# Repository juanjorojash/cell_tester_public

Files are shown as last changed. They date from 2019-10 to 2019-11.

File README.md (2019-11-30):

Electrochemical Cell Charger/Discharger/Tester
============

### Most recent version of this repository can be found in: ###

* [GitHub](https://github.com/juanjorojash/cell_tester_public/)

### Documentation ###

* Full documentation in HTLM version can be found in **[repository directory]/documentation/htlm/index.htlm**

### What is this repository for? ###

* This repository was created to be used in conjuction with the integrated system known as "Charger_discharger.V5". The latest . It was created to control the PIC16F1786 installed for feedback control and serial logging.
* Hardware version: Charger_discharger.V5
* PCB design files  located in **[repository directory]/board/**

### How do I get set up? ###

* Connect usign serial cable model "TTL-232R-5V-AJ". 
* **Serial terminal** Start with the following settings BR:57600 kbps, Data: 8 bit, Parity: none, Stop bits: 1, Flow control: none. Press "ESC" to restart and show the main menu. Set the desired configuration following the instructions.
* **LabView logger program** A program for receiving, saving and plotting the test data is included in the repository, in the directory **labview_logger/logger.exe**. The following programs are needed in order to run this program in a PC that **does not** have LabView installed:
	* [LabVIEW Run-Time Engine 2016 - (64-bit)](http://www.ni.com/download/labview-run-time-engine-2016/6067/en/) 
	* [NI-VISA Run-Time Engine 16.0](http://www.ni.com/download/ni-visa-run-time-engine-16.0/6188/en/)
The program creates the directory **c:/logger_data** to store the data.

### Contribution guidelines ###

* If you want to propose a review or need to modify the code for any reason first fork this [repository](https://github.com/juanjorojash/cell_tester_public/) in your PC and create a new branch for your changes. Once your changes are complete and fully tested ask the administrator permission to push this new branch into the source.
* If you just want to do local changes instead you can download a zip version of the repository and do all changes locally in your PC. 

### Who do I talk to? ###

* [Juan J. Rojas](mailto:juan.rojas@itcr.ac.cr)

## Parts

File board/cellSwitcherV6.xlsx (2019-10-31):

Part List |  |  |  |  |  |  |  | To take from inventory |  |  |  |  |  | To buy |  |  |  |  |  |  |  |  |  |  |  | FOR RS |  | FOR PBAN |  |  |  |  |  | SMD / DIP | Package
Qty | Name | Device | Value | Package | Parts | SMD / DIP | Pads / Pins | Bag | Available | Need | Balance | Specifications | Manufacturer | Vendor | Vendor SN | Manufacurer PN | Package type | Needed | Minimum | Actual | Inventory before | Inventory now | Unit cost | Total
4 | NPN transistor | BC818K-40 |  | SOT-23 | BJT1, BJT2, BJT3, BJT4 | SMD | 3 | A28 | 93 | 30 | 63 |  | Infineon |  |  | BC818K40E6327HTSA1 |  |  |  |  |  |  |  |  |  |  |  | Infineon | NPN transistor | BC818K40E6327HTSA1 | BJT1, BJT2, BJT3, BJT4 | 4 | 3 | SMD | SOT-23
1 | Non-polarized capacitor | NONPOL_CAP-0603 | 1n | C0603 | C1 | SMD | 2 | B37 | 93 | 12 | 81 |  | TDK |  |  | C1608X7R1H102K080AE |  |  |  |  |  |  |  |  |  |  |  | TDK | Non-polarized capacitor | C1608X7R1H102K080AE | C1 | 1 | 2 | SMD | C0603
2 | Non-polarized capacitor | NONPOL_CAP-0603 | 0.1u | C0603 | C2, C3 | SMD | 2 | B03 | 93 | 18 | 75 |  | TDK |  |  | C1608X8R1H104K080AB |  |  |  |  |  |  |  |  |  |  |  | TDK | Non-polarized capacitor | C1608X8R1H104K080AB | C2, C3 | 2 | 2 | SMD | C0603
1 | Non-polarized capacitor | NONPOL_CAP-0603 | 0.33u | C0603 | C4 | SMD | 2 | A25 | 34 | 12 | 22 |  | Murata |  |  | GRM21BR71C334KA01L |  |  |  |  |  |  |  |  |  |  |  | Murata | Non-polarized capacitor | GRM21BR71C334KA01L | C4 | 1 | 2 | SMD | C0603
1 | Non-polarized capacitor | NONPOL_CAP-0603 | 1u | C0603 | C5 | SMD | 2 | B04 | 8 | 12 | -4 |  | TDK |  |  | CGA4J3X7R1H105K125AB |  |  |  |  |  |  |  |  |  |  |  | TDK | Non-polarized capacitor | CGA4J3X7R1H105K125AB | C5 | 1 | 2 | SMD | C0603
1 | Non-polarized capacitor | NONPOL_CAP-0603 | 10u | C0603 | C6 | SMD | 2 | B06 | 32 | 12 | 20 |  | Murata |  |  | GRM188R61E106MA73D |  |  |  |  |  |  |  |  |  |  |  | Murata | Non-polarized capacitor | GRM188R61E106MA73D | C6 | 1 | 2 | SMD | C0603
2 | Li-Ion cell holder | 2_18650_HOLDER |  |  | CH1, CH2 | DIP | 2 | C1 | 12 | 9 | 3 |  | Keystone |  |  | 1049P |  |  |  |  |  |  |  |  |  |  |  | Keystone | Li-Ion cell holder | 1049P | CH1, CH2 | 2 | 2 | DIP
2 | Ni-MH cell holder | 2_AA_HOLDER |  |  | CH1, CH2 | DIP | 2 |  |  |  |  | Bulgin PCB mounting battery holder, AA size X 1 BX0035 AA battery 1 PCB | Bulgin | RS | 489-908 | BX0035 |  | 9 | 1 | 9 | 0 | 0 | ¥392.00 | ¥3528.00 | https://jp.rs-online.com/web/p/battery-holders-mounts/0489908/ | 489-908 | 9 | Bulgin | Ni-MH cell holder | BX0035 | CH1, CH2 | 2 | 2 | DIP
1 | Connector | TMM-110-01-F-D-RA |  |  | CON1 | DIP | 20 |  |  |  |  | 20 Positions Header Connector 0.079 "(2.00 mm) Through Hole, Right Angle Gold | SAMTEC | Digi-Key | TMM-110-01-FD-RA-ND | TMM-110-01-FD-RA |  | 12 | 1 | 12 | 0 | 0 | ¥229.00 | ¥2748.00 | https://www.digikey.jp/product-detail/ja/samtec-inc/TMM-110-01-F-D-RA/TMM-110-01-F-D-RA-ND/2685424 | TMM-110-01-FD-RA-ND | 12 | SAMTEC | Connector | TMM-110-01-FD-RA | CON1 | 1 | 20 | DIP
4 | Switching diode | BAQ133-GS08 |  | SOD08 | D1, D2, D3, D4 | SMD | 2 | A44 | 78 | 30 | 48 |  | Vishay |  |  | BAQ133-GS08 |  |  |  |  |  |  |  |  |  |  |  | Vishay | Switching diode | BAQ133-GS08 | D1, D2, D3, D4 | 4 | 2 | SMD | SOD08
1 | Fuse holder | FUSEHOLDER |  |  | F1 | DIP | 2 | A38 | 10 | 12 | -2 | Schurter PCB mounting fuse holder 10A for 5 x 20 mm cartridge fuse 250V ac 0031.8201 | Schurter | RS | 176-9047 | 31.8201 |  | 2 | 10 | 10 | 0 | 8 | ¥97.40 | ¥974.00 | https://jp.rs-online.com/web/p/pcb-mounts/1769047/ | 176-9047 | 10 | Schurter | Fuse holder | 31.8201 | F1 | 1 | 2 | DIP
4 | Relay | RTE24005F |  |  | K1, K2, K3, K4 | DIP | 8 | A66 | 24 | 30 | -6 | TE Connectivity Relay 5V dc, 2c contact PCB mounting type | TE Connectivity | RS | 782-1261 | RTE24005F |  | 6 | 1 | 6 | 0 | 0 | ¥316.00 | ¥1896.00 | https://jp.rs-online.com/web/p/pcb-mounts/1769047/ | 782-1261 | 6 | TE Connectivity | Relay | RTE24005F | K1, K2, K3, K4 | 4 | 8 | DIP
4 | LED | LGR971 |  | SML0805 | LED1, LED2, LED3, LED4 | SMD | 2 | A49 | 32 | 30 | 2 |  | OSRAM Opto Semiconductors |  |  | LGR971 |  |  |  |  |  |  |  |  |  |  |  | OSRAM Opto Semiconductors | LED | LGR971 | LED1, LED2, LED3, LED4 | 4 | 2 | SMD | SML0805
1 | Muxer | ADG704BRM |  | MSOP10 | MUX1 | SMD | 10 | A52 | 7 | 12 | -5 | Analog Devices Single 4: 1 Multiplexer 3 V, 5 V, 10-Pin MSOP | Analog Devices | RS | 523-8761 | ADG704BRMZ |  | 5 | 1 | 5 | 0 | 0 | ¥327.00 | ¥1635.00 | https://jp.rs-online.com/web/p/multiplexer-switch-ics/5238761/ | 523-8761 | 5 | Analog Devices | Muxer | ADG704BRMZ | MUX1 | 1 | 10 | SMD | MSOP10
1 | NAND gate | SN74LVC2G00DCUT |  | VSSOP-8 | NAND1 | SMD | 8 | A48 | 16 | 12 | 4 |  | Texas Instruments |  |  | SN74LVC2G00DCUT |  |  |  |  |  |  |  |  |  |  |  | Texas Instruments | NAND gate | SN74LVC2G00DCUT | NAND1 | 1 | 8 | SMD | VSSOP-8
1 | OptoCoupler | PS2502-4 |  | DIL16 | OK1 | DIP | 16 | A50 | 12 | 12 | 0 |  | Renesas Electronics |  |  | PS2502-4-A |  |  |  |  |  |  |  |  |  |  |  | Renesas Electronics | OptoCoupler | PS2502-4-A | OK1 | 1 | 16 | DIP | DIL16
4 | Resistor | RESISTOR-0603 | 1k | R0603 | R1, R2, R3, R4 | SMD | 2 |  |  |  |  | TE Connectivity Thick Film Surface Mount Resistors, 0.1 W, 1 kΩ, ± 1% | TE Connectivity | RS | 213-2266 | CRG0603F1K0 |  | 30 | 50 | 50 | 0 | 20 | ¥3.90 | ¥195.00 | https://jp.rs-online.com/web/p/surface-mount-fixed-resistors/2132266 | 213-2266 | 50 | TE Connectivity | Resistor | CRG0603F1K0 | R1, R2, R3, R4 | 4 | 2 | SMD | R0603
4 | Resistor | RESISTOR-0603 | 510 | R0603 | R1.1, R2.1, R3.1, R4.1 | SMD | 2 | A93 | 29 | 30 | -1 |  | Vishay |  |  | CRCW0603510RFKEA |  |  |  |  |  |  |  |  |  |  |  | Vishay | Resistor | CRCW0603510RFKEA | R1.1, R2.1, R3.1, R4.1 | 4 | 2 | SMD | R0603
1 | Resistor | RESISTOR-0603 | 0 | R0603 | R5 | SMD | 2 | B22 | 27 | 12 | 15 |  | Vishay |  |  | CRCW06030000Z0EB |  |  |  |  |  |  |  |  |  |  |  | Vishay | Resistor | CRCW06030000Z0EB | R5 | 1 | 2 | SMD | R0603
1 | Regulator | NCV7805BD2TG |  | D2PAK-3 | REG2 | SMD | 3 | B32 | 27 | 12 | 15 |  | ON Semiconductor |  |  | NCV7805BD2TG |  |  |  |  |  |  |  |  |  |  |  | ON Semiconductor | Regulator | NCV7805BD2TG | REG2 | 1 | 3 | SMD | D2PAK-3
4 | Temperature sensor | STLM20DD9F |  | UDFN-4L | TS1, TS2, TS3, TS4 | SMD | 4 |  |  |  |  | STMicroelectronics Temperature Sensor IC, ± 1.5 ° C, Analog, 2.4 to 5.5 V, 4-Pin UDFN Temperature | STMicroelectronics | RS | 686-4973 | STLM20DD9F | UDFN-4L | 30 | 5 | 30 | 0 | 0 | ¥90.80 | ¥2724.00 | https://jp.rs-online.com/web/p/temperature-sensors-humidity-sensors/6864973/ | 686-4973 | 30 | STMicroelectronics | Temperature sensor | STLM20DD9F | TS1, TS2, TS3, TS4 | 4 | 4 | SMD | UDFN-4L
3 | Fuses |  | 4A |  |  |  |  |  |  |  |  | Littelfuse glass tube fuse 4A (time lag) 239 series 5x20mm 5 x 20mm 125V ac | Littlefuse | RS | 523-4725 | 0239004.MXP |  | 24 | 30 | 30 | 0 | 6 | ¥81.40 | ¥2442.00 | https://jp.rs-online.com/web/p/cartridge-fuses/5234725/ | 523-4725 | 30
1 | PCB fabrication |  |  |  |  |  |  |  |  |  |  | PCB fabrication - 2 layers - With soldering service | P-ban | P-ban |  |  |  | 1 | 1 | 1 | 0 | 0 |  | ¥0.00
TOTAL |  | ¥16142.00

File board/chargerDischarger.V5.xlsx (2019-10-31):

Part List |  |  |  |  |  |  |  | To take from inventory |  |  |  |  |  | To buy |  |  |  |  |  |  |  |  |  |  |  | FOR RS |  | FOR PBAN |  |  |  |  |  | SMD / DIP | Package
Qty | Name | Device | Value | Package | Parts | SMD / DIP | Leads / Pins | Bag | Available | Need | Balance | Specifications | Manufacturer | Vendor | Vendor SN | Manufacurer PN | Package type | Needed | Minimum | Actual | Inventory before | Inventory now | Unit cost | Total
3 | NPN transistor | BC818K-40 |  | SOT-23 | BJT101, BJT102, BJT103 | SMD | 3 | A28 | 105 | 12 | 93 |  | Infineon |  |  | BC818K40E6327HTSA1 | SOT-23 |  |  |  |  |  |  |  |  |  |  | Infineon | NPN transistor | BC818K40E6327HTSA1 | BJT101, BJT102, BJT103 | 3 | 3 | SMD | SOT-23
13 | Non-polarized capacitor | NONPOL_CAP-0603 | 1u | C0603 | C1, C3, C5, C6, C7, C101, C102, C103, C210, C214, C302, C304, C403 | SMD | 2 | B33 |  |  |  | TDK MLCC 1μF 50V dc ± 10% | TDK | RS | 903-8720 | CGA4J3X7R1H105K125AB | C0603 | 42 | 50 | 50 | 0 | 8 | ¥26.76 | ¥1338.00 | https://jp.rs-online.com/web/p/mlccs-multilayer-ceramic-capacitors/9038720/ | 903-8720 | 50 | TDK | Non-polarized capacitor | CGA4J3X7R1H105K125AB | C1, C3, C5, C6, C7, C101, C102, C103, C210, C214, C302, C304, C403 | 13 | 2 | SMD | C0603
4 | Non-polarized capacitor | NONPOL_CAP-0603 | 10u | C0603 | C2, C10, C303, C405 | SMD | 2 |  |  |  |  | Murata MLCC 10μF 25V dc ± 20% | Murata | RS | 790-2723 | GRM188R61E106MA73D | C0603 | 15 | 25 | 25 | 0 | 10 | ¥29.12 | ¥728.00 | https://jp.rs-online.com/web/p/mlccs-multilayer-ceramic-capacitors/7902723/ | 790-2723 | 25 | Murata | Non-polarized capacitor | GRM188R61E106MA73D | C2, C10, C303, C405 | 4 | 2 | SMD | C0603
3 | Non-polarized capacitor | NONPOL_CAP-0603 | 10u | C1210 | C201, C202, C203 | SMD | 2 |  |  |  |  | TDK MLCC 10μF 50V dc ± 10% | TDK | RS | 915-5446 | CGA6P3X7S1H106K250AE | C1210 | 12 | 25 | 25 | 0 | 13 | ¥210.20 | ¥5255.00 | https://jp.rs-online.com/web/p/mlccs-multilayer-ceramic-capacitors/9155446/ | 915-5446 | 25 | TDK | Non-polarized capacitor | CGA6P3X7S1H106K250AE | C201, C202, C203 | 3 | 2 | SMD | C1210
6 | Polarized capacitor | POL_CAP-7343 | 33u | C7343 | C204, C205, C206, C215, C216, C217 | SMD | 2 | A82 |  |  |  | KEMET 33μF 25V dc Tantalum Capacitor Polymer Solid ±20% Tolerance T521 Series | KEMET | RS | 121-3317 | T521D336M025ATE040 | C7343 | 21 | 50 | 50 | 0 | 29 | ¥121.40 | ¥6070.00 | https://jp.rs-online.com/web/p/tantalum-capacitors/1213317/ | 121-3317 | 50 | KEMET | Polarized capacitor | T521D336M025ATE040 | C204, C205, C206, C215, C216, C217 | 6 | 2 | SMD | C7343
1 | Non-polarized capacitor | NONPOL_CAP-0603 | 10n | C0603 | C211 | SMD | 2 | A85 | 95 | 6 | 89 |  | Murata |  |  | GRM1885C1H103JA01D | C0603 |  |  |  |  |  |  |  |  |  |  | Murata | Non-polarized capacitor | GRM1885C1H103JA01D | C211 | 1 | 2 | SMD | C0603
6 | Non-polarized capacitor | NONPOL_CAP-0603 | 0.1u | C0603 | C4, C207, C218, C305, C501, C502 | SMD | 2 |  |  |  |  | TDK MLCC 100nF 50V dc ± 10% | TDK | RS | 915-9237 | C1608X8R1H104K080AB | C0603 | 21 | 100 | 100 | 0 | 79 | ¥7.74 | ¥774.00 | https://jp.rs-online.com/web/p/mlccs-multilayer-ceramic-capacitors/9159237 | 915-9237 | 100 | TDK | Non-polarized capacitor | C1608X8R1H104K080AB | C4, C207, C218, C305, C501, C502 | 6 | 2 | SMD | C0603
1 | Non-polarized capacitor | NONPOL_CAP-0603 | 0.33u | C0603 | C401 | SMD | 2 | A25 | 95 | 6 | 89 |  | Murata |  |  | GRM21BR71C334KA01L | C0603 |  |  |  |  |  |  |  |  |  |  | Murata | Non-polarized capacitor | GRM21BR71C334KA01L | C401 | 1 | 2 | SMD | C0603
1 | Non-polarized capacitor | POL_CAP-7343 | 100u | D6.3_AEC | C601 | SMD | 2 | A86 | 6 | 6 | 0 |  | Nichicon |  |  | UWT1C101MCL1GB | D6.3_AEC |  |  |  |  |  |  |  |  |  |  | Nichicon | Non-polarized capacitor | UWT1C101MCL1GB | C601 | 1 | 2 | SMD | D6.3_AEC
1 | Non-polarized capacitor | NONPOL_CAP-0603 | 1n | C0603 | C8 | SMD | 2 |  |  |  |  | TDK MLCC 1nF 50V dc ± 10% | TDK | RS | 915-9211 | C1608X7R1H102K080AE | C0603 | 6 | 100 | 100 | 0 | 94 | ¥5.98 | ¥598.00 | https://jp.rs-online.com/web/p/mlccs-multilayer-ceramic-capacitors/9159211 | 915-9211 | 100 | TDK | Non-polarized capacitor | C1608X7R1H102K080AE | C8 | 1 | 2 | SMD | C0603
1 | Audio jack | AUDIO_JACK-3.5MM |  |  | COMM | DIP | 4 | A87 | 2 | 6 | -4 | Lumberg phone jack (female) 3.5 mm through-hole stereo | Lumberg | RS | 505-1479 | KLBR 4 |  | 4 | 1 | 4 | 0 | 0 | ¥280.00 | ¥1120.00 | https://jp.rs-online.com/web/p/jack-plugs/5051479 | 505-1479 | 4 | Lumberg | Audio jack | KLBR 4 | COMM | 1 | 4 | DIP
1 | Connector | B6B-EH-A |  |  | CON1 | DIP | 6 | A88 | 2 | 6 | -4 | Pin header for JST board connection EH series 6 poles 2.5 mm single row straight | JST | RS | 515-1434 | B6B-EH-A (LF) (SN) |  | 4 | 10 | 10 | 0 | 6 | ¥25.50 | ¥255.00 | https://jp.rs-online.com/web/p/pcb-headers/5151434 | 515-1434 | 10 | JST | Connector | B6B-EH-A (LF) (SN) | CON1 | 1 | 6 | DIP
1 | Connector | SQT-110-01-F-D-RA |  |  | CON2 | DIP | 20 |  |  |  |  | Samtec Discrete Socket SQT Series 2mm 20 Pole 2 Row Through Hole SQT-110-01-FD-RA | SAMTEC | RS | 180-1847 | SQT-110-01-FD-RA |  | 6 | 1 | 6 | 0 | 0 | ¥467.00 | ¥2802.00 | https://jp.rs-online.com/web/p/pcb-sockets/1801847/ | 180-1847 | 6 | SAMTEC | Connector | SQT-110-01-FD-RA | CON2 | 1 | 20 | DIP
3 | Switching diode | BAQ133-GS08 |  | SOD08 | D101, D102, D103 | SMD | 2 | A44 | 90 | 12 | 78 |  | Vishay |  |  | BAQ133-GS08 | SOD08 |  |  |  |  |  |  |  |  |  |  | Vishay | Switching diode | BAQ133-GS08 | D101, D102, D103 | 3 | 2 | SMD | SOD08
1 | Schottky diode | SCHOTTKY_DIODE-BAT42W |  | SOD123 | D202 | SMD | 2 | A26 | 97 | 6 | 91 |  | DiodesZetex |  |  | BAT42W-7-F | SOD123 |  |  |  |  |  |  |  |  |  |  | DiodesZetex | Schottky diode | BAT42W-7-F | D202 | 1 | 2 | SMD | SOD123
1 | Op-Amp | MAX4198 |  | SOIC-8 | DA501 | SMD | 8 | A92 | 3 | 6 | -3 | IC OPAMP DIFF 1 CIRCUIT 8SOIC | Maxim Integrated | Digi-Key | MAX4198ESA+-ND | MAX4198ESA+-ND | SOIC-8 | 3 | 1 | 3 | 0 | 0 | ¥347.00 | ¥1041.00 | https://www.digikey.com/product-detail/en/maxim-integrated/MAX4198ESA/MAX4198ESA-ND/1702090 | MAX4198ESA+-ND | 3 | Maxim Integrated | Op-Amp | MAX4198ESA+-ND | DA501 | 1 | 8 | SMD | SOIC-8
1 | Dual MOSFET Driver | MCP14628-E/SN |  | SOIC-8 | DR200 | SMD | 8 |  |  |  |  | Microchip MOSFET Driver Dual 2A, 4.5-5.5V 8-Pin SOIC Inverted, Non-Inverted MCP14628-E / SN | Microchip | RS | 668-4219 | MCP14628-E / SN | SOIC-8 | 6 | 2 | 6 | 0 | 0 | ¥205.50 | ¥1233.00 | https://jp.rs-online.com/web/p/mosfet-drivers/6684219 | 668-4219 | 6 | Microchip | Dual MOSFET Driver | MCP14628-E / SN | DR200 | 1 | 8 | SMD | SOIC-8
2 | Fuse holder | FUSEHOLDER |  |  | F1,F2 | DIP | 2 | A38 | 19 | 9 | 10 |  | Schurter |  |  | 31.8201 |  |  |  |  |  |  |  |  |  |  |  | Schurter | Fuse holder | 31.8201 | F1,F2 | 2 | 2 | DIP
1 | Common mode choke | ACM9070-701 |  |  | FIL601 | SMD | 4 |  |  |  |  | TDK common mode choke coil ACM 10 mΩ | TDK | RS | 916-4144 | ACM9070-701-2PL-TL01 |  | 6 | 2 | 6 | 0 | 0 | ¥247.00 | ¥1482.00 | https://jp.rs-online.com/web/p/emi-rfi-inductor-components/9164144/ | 916-4144 | 6 | TDK | Common mode choke | ACM9070-701-2PL-TL01 | FIL601 | 1 | 4 | SMD
1 | Relay | ORWH |  |  | K101 | DIP | 5 | A72 | 8 | 6 | 2 |  | TE Connectivity |  |  | ORWH-SH-105D1F |  |  |  |  |  |  |  |  |  |  |  | TE Connectivity | Relay | ORWH-SH-105D1F | K101 | 1 | 5 | DIP
1 | Relay | RT424F05054 |  |  | K102 | DIP | 9 |  |  |  |  | TE Connectivity Latching Relay DPDT 5V dc | TE Connectivity | RS | 680-3883P | RT424F05 |  | 6 | 1 | 6 | 0 | 0 | ¥870.00 | ¥5220.00 | https://jp.rs-online.com/web/p/latching-relays/6803883P/ | 680-3883P | 6 | TE Connectivity | Relay | RT424F05 | K102 | 1 | 9 | DIP
2 | Power Inductor | INDUCTOR-60B8683C | 68u |  | L203, L204 | SMD | 2 |  |  |  |  | Murata Power Solutions Wirewound Inductors (face mount), 68 μH, 9A, 27 x 19.5 x 20 mm | Murata | RS | 749-6405 | 60B683C |  | 9 | 1 | 9 | 0 | 0 | ¥356.00 | ¥3204.00 | https://jp.rs-online.com/web/p/wire-wound-surface-mount-inductors/7496405/ | 749-6405 | 9 | Murata | Power Inductor | 60B683C | L203, L204 | 2 | 2 | SMD
3 | LED | LGR971 |  | SML0805 | LED101, LED102, LED103 | SMD | 2 | A49 | 44 | 12 | 32 |  | OSRAM |  |  | LGR971 | SML0805 |  |  |  |  |  |  |  |  |  |  | OSRAM | LED | LGR971 | LED101, LED102, LED103 | 3 | 2 | SMD | SML0805
2 | N-Channel MOSFET | SI4154DY |  | SOIC-8 | MF201, MF202 | SMD | 8 |  |  |  |  | N-Ch MOSFET SO-8 BWL 40 V 3.3 mohm @ 10 V- | Vishay | RS | 180-7965 | SI4154DY-T1-GE3 | SOIC-8 | 9 | 10 | 10 | 0 | 1 | ¥175.80 | ¥1758.00 | https://jp.rs-online.com/web/p/mosfets/1807965/ | 180-7965 | 10 | Vishay | N-Channel MOSFET | SI4154DY-T1-GE3 | MF201, MF202 | 2 | 8 | SMD | SOIC-8
3 | OptoCoupler | PS2502-1 |  | DIL04 | OK101, OK102, OK103 | DIP | 4 |  |  |  |  | Isocom Photocoupler AC input 1, 4-Pin through hole mounting | Isocom | RS | 161-1266 | PS2502-1X | DIL04 | 12 | 20 | 20 | 0 | 8 | ¥64.65 | ¥1293.00 | https://jp.rs-online.com/web/p/optocouplers/1611266/ | 161-1266 | 20 | Isocom | OptoCoupler | PS2502-1X | OK101, OK102, OK103 | 3 | 4 | DIP | DIL04
1 | Power jack | 722RA |  |  | PC1 | DIP | 3 |  |  |  |  | Switchcraft DC Power Socket 2mm 5A Through Hole 12 V dc 722RA | Switchcraft | RS | 705-1516 | 722RA |  | 6 | 1 | 6 | 0 | 0 | ¥345.00 | ¥2070.00 | https://jp.rs-online.com/web/p/optocouplers/1611266/ | 705-1516 | 6 | Switchcraft | Power jack | 722RA | PC1 | 1 | 3 | DIP
1 | 8-bit MCU | PIC16F1786-I/SS |  | SPDIP-28 | PIC1 | DIP | 28 |  |  |  |  | Microchip Microcomputer PIC16F 8-bit RISC, 28-Pin SDPIP | Microchip | RS | 803-2434 | PIC16F1786-I / SP | SPDIP-28 | 6 | 10 | 10 | 0 | 4 | ¥311.00 | ¥3110.00 | https://jp.rs-online.com/web/p/microcontrollers/8032434 | 803-2434 | 10 | Microchip | 8-bit MCU | PIC16F1786-I / SP | PIC1 | 1 | 28 | DIP | SPDIP-28
3 | Power Resistor | TO-220_RESISTOR | 1 | TO-220 | PR701, PR702, PR703 | DIP | 4 |  |  |  |  | Vishay Power Resistor LTO 50 Series 1 Ω 50 W ą 5% | Vishay | RS | 532-8369 | LTO 050 F 1 R 000 JTE 3 | TO-220 | 12 | 1 | 12 | 0 | 0 | ¥838.00 | ¥10056.00 | https://jp.rs-online.com/web/p/through-hole-fixed-resistors/5328369/ | 532-8369 | 12 | Vishay | Power Resistor | LTO 050 F 1 R 000 JTE 3 | PR701, PR702, PR703 | 3 | 4 | DIP | TO-220
2 | Resistor | RESISTOR-0603 | 0 | R0603 | R1, R2 | SMD | 2 | B22 |  |  |  | Vishay thick film surface mount resistor, 0.1 W, 0 Ω, ± 1% | Vishay | RS | 678-9670 | CRCW06030000Z0EB | R0603 | 9 | 50 | 50 | 0 | 41 | ¥1.34 | ¥67.00 | https://jp.rs-online.com/web/p/surface-mount-fixed-resistors/6789670/ | 678-9670 | 50 | Vishay | Resistor | CRCW06030000Z0EB | R1, R2 | 2 | 2 | SMD | R0603
4 | Resistor | RESISTOR-0603 | 1k | R0603 | R101, R103, R106, R202 | SMD | 2 | A21 | 26 | 15 | 11 |  | TE Connectivity |  |  | CRG0603F1K0 | R0603 |  |  |  |  |  |  |  |  |  |  | TE Connectivity | Resistor | CRG0603F1K0 | R101, R103, R106, R202 | 4 | 2 | SMD | R0603
3 | Resistor | RESISTOR-0603 | 510 | R0603 | R102, R104, R107 | SMD | 2 | A93 | 41 | 12 | 29 |  | Vishay |  |  | CRCW0603510RFKEA | R0603 |  |  |  |  |  |  |  |  |  |  | Vishay | Resistor | CRCW0603510RFKEA | R102, R104, R107 | 3 | 2 | SMD | R0603
1 | Resistor | RESISTOR-0603 | 10M | R0603 | R105 | SMD | 2 | A22 | 40 | 6 | 34 |  | Vishay |  |  | CRCW060310M0FKEA | R0603 |  |  |  |  |  |  |  |  |  |  | Vishay | Resistor | CRCW060310M0FKEA | R105 | 1 | 2 | SMD | R0603
1 | Resistor | RESISTOR-0603 | 200 | R0603 | R4 | SMD | 2 |  |  |  |  | KOA Thick Film Surface Mount Resistors, 0.125 W, 200 Ω, ± 1% | KOA | RS | 631-6222 | RK73H1JTTD2000F | R0603 | 6 | 50 | 50 | 0 | 44 | ¥7.96 | ¥398.00 | https://jp.rs-online.com/web/p/surface-mount-fixed-resistors/6316222/ | 631-6222 | 50 | KOA | Resistor | RK73H1JTTD2000F | R4 | 1 | 2 | SMD | R0603
1 | Regulator | NCV7805BD2TG |  | D2PAK-3 | REG402 | SMD | 3 |  |  |  |  | ON Semiconductor Positive Voltage 3-Terminal Regulator 5 V 1A Fixed Output Surface Mount D2PAK 3-Pin | ON Semiconductor | RS | 785-7428 | NCV7805BD2TG | D2PAK-3 | 6 | 10 | 10 | 0 | 4 | ¥82.20 | ¥822.00 | https://jp.rs-online.com/web/p/linear-voltage-regulators/7857428 | 785-7428 | 10 | ON Semiconductor | Regulator | NCV7805BD2TG | REG402 | 1 | 3 | SMD | D2PAK-3
1 | Hall-effect current sensor | ACS723-05AB-T |  | SOIC-8 | SEN301 | SMD | 8 |  |  |  |  | Hall-effect current sensor IC, 8-pin SOIC | Allegro Microsystems | RS | 866-0767 | ACS723LLCTR-05AB-T | SOIC-8 | 6 | 10 | 10 | 0 | 4 | ¥647.00 | ¥6470.00 | https://jp.rs-online.com/web/p/current-sensors/8660767/ | 866-0767 | 10 | Allegro Microsystems | Hall-effect current sensor | ACS723LLCTR-05AB-T | SEN301 | 1 | 8 | SMD | SOIC-8
2 | Voltage reference | REF195GSZ |  | SOIC-8 | VREF1, VREF302 | SMD | 8 |  |  |  |  | Analog Devices Reference Voltage IC, Output: 5V Surface Mount, 8-pin SOIC | Analog Devices | RS | 523-7011 | REF195GSZ | SOIC-8 | 9 | 10 | 10 | 0 | 1 | ¥400.00 | ¥4000.00 | https://jp.rs-online.com/web/p/voltage-references/5237011/ | 523-7011 | 10 | Analog Devices | Voltage reference | REF195GSZ | VREF1, VREF302 | 2 | 8 | SMD | SOIC-8
3 | Heatsink |  |  |  |  |  |  |  |  |  |  | For RS Pro heat sink transistor, 20 x 35 x 20 mm | RS Pro | RS | 263-251 | 263-251 |  | 10 | 10 | 10 | 0 | 0 | ¥224.00 | ¥2240.00 | https://jp.rs-online.com/web/p/heatsinks/0263251/ | 263-251 | 10
1 | FTDI chip |  |  |  |  |  |  |  |  |  |  | FTDI Chip Interface Development Kit 5 V TTL 3.5 mm Jack USB-UART Cable | FTDI Chip | RS | 687-7774 | TTL-232R-5V-AJ |  | 3 | 1 | 3 | 0 | 0 | ¥2397.00 | ¥7191.00 | https://jp.rs-online.com/web/p/interface-development-kits/6877774/ | 687-7774 | 3
1 | Adaptor |  |  |  |  |  |  |  |  |  |  | 7.5V 24W AC/DC External Wall Mount Adapter Fixed Blade Input | Triad Magnetics | Digi-Key | 237-1391-ND | WSU075-3200 |  | 4 | 1 | 4 | 0 | 0 | ¥1891.00 | ¥7564.00 | https://www.digikey.jp/products/en?keywords=237-1391-ND | 237-1391-ND | 4
1 | PCB fabrication |  |  |  |  |  |  |  |  |  |  | PCB fabrication - 2 layers - With soldering service | P-ban | P-ban |  |  |  | 1 | 1 | 1 | 0 | 0 |  | ¥0.00 |  |  | 1
TOTAL |  | ¥78159.00

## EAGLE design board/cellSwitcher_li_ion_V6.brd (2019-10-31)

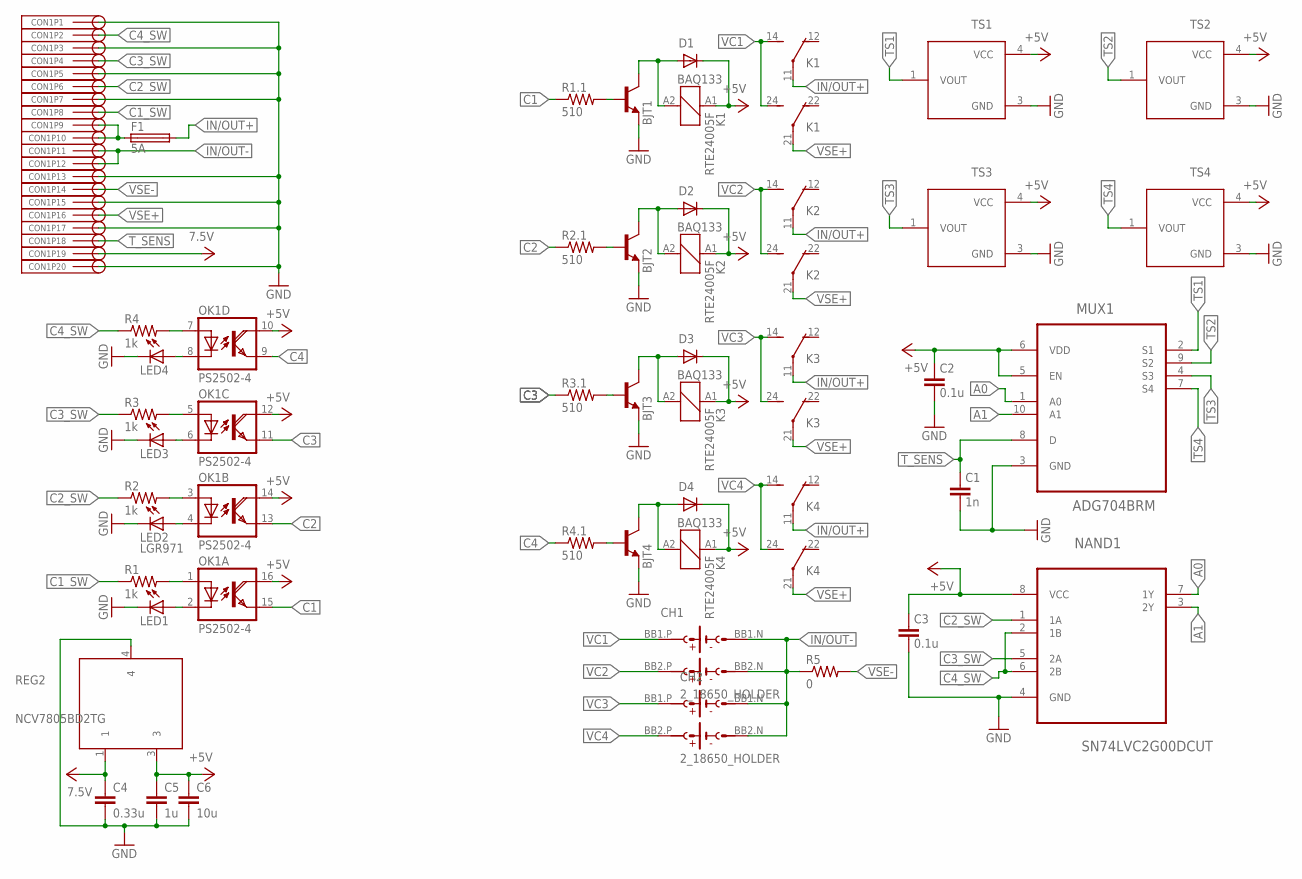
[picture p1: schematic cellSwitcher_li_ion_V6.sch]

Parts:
BJT1, BJT2, BJT3, BJT4: BC818K-40; SOT-23
C1: 1n; C0603
C2, C3: 0.1u; C0603
C4: 0.33u; C0603
C5: 1u; C0603
C6: 10u; C0603
CH1, CH2: 2_18650_HOLDER
CON1: TMM-110-01-F-D-RA
D1, D2, D3, D4: BAQ133; SOD08
F1: 5A; SH22,5
K1, K2, K3, K4: RTE24005F
LED1, LED2, LED3, LED4: LGR971; SML0805
MUX1: ADG704BRM; MSOP10
NAND1: SN74LVC2G00DCUT; VSSOP-8
OK1: PS2502-4; DIL16
R1, R2, R3, R4: 1k; R0603
R1.1, R2.1, R3.1, R4.1: 510; R0603
R5: 0; R0603
REG2: NCV7805BD2TG; D2PAK-3
TS1, TS2, TS3, TS4: STLM20DD9F; UDFN-4L

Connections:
7.5V: C4.1, CON1.19, REG2.1
+5V: C2.1, C3.1, C5.1, C6.1, D1.C, D2.C, D3.C, D4.C, K1.A1 (1), K2.A1 (1), K3.A1 (1), K4.A1 (1), MUX1.5 (EN), MUX1.6 (VDD), NAND1.8 (VCC), OK1.10 (COL), OK1.12 (COL), OK1.14 (COL), OK1.16 (COL), REG2.3, TS1.4 (VCC), TS2.4 (VCC), TS3.4 (VCC), TS4.4 (VCC)
A0: MUX1.1 (A0), NAND1.7 (1Y)
A1: MUX1.10 (A1), NAND1.3 (2Y)
C1: OK1.15 (EMI), R1.1.1
C1_SW: CON1.8, R1.1
C2: OK1.13 (EMI), R2.1.1
C2_SW: CON1.6, NAND1.1 (1A), R2.1
C3: OK1.11 (EMI), R3.1.1
C3_SW: CON1.4, NAND1.5 (2A), R3.1
C4: OK1.9 (EMI), R4.1.1
C4_SW: CON1.2, NAND1.2 (1B), NAND1.6 (2B), R4.1
GND: BJT1.2 (E), BJT2.2 (E), BJT3.2 (E), BJT4.2 (E), C1.2, C2.2, C3.2, C4.2, C5.2, C6.2, CON1.1, CON1.3, CON1.5, CON1.7, CON1.13, CON1.15, CON1.17, CON1.20, LED1.C, LED2.C, LED3.C, LED4.C, MUX1.3 (GND), NAND1.4 (GND), REG2.4, TS1.3 (GND), TS2.3 (GND), TS3.3 (GND), TS4.3 (GND)
IN/OUT+: F1.2, K1.11 (COM), K2.11 (COM), K3.11 (COM), K4.11 (COM)
IN/OUT+1: CON1.9, CON1.10, F1.1
IN/OUT-: CH1.BB1.N (B1.N), CH1.BB2.N (B2.N), CH2.BB1.N (B1.N), CH2.BB2.N (B2.N), CON1.11, CON1.12, R5.1
unnamed: BJT1.1 (B), R1.1.2
unnamed: BJT2.1 (B), R2.1.2
unnamed: BJT3.1 (B), R3.1.2
unnamed: BJT3.3 (C), D3.A, K3.A2 (2)
unnamed: LED1.A, OK1.2 (C)
unnamed: LED2.A, OK1.4 (C)
unnamed: LED3.A, OK1.6 (C)
unnamed: LED4.A, OK1.8 (C)
unnamed: OK1.7 (A), R4.2
unnamed: OK1.5 (A), R3.2
unnamed: OK1.3 (A), R2.2
unnamed: OK1.1 (A), R1.2
unnamed: BJT1.3 (C), D1.A, K1.A2 (2)
unnamed: BJT2.3 (C), D2.A, K2.A2 (2)
unnamed: BJT4.1 (B), R4.1.2
unnamed: BJT4.3 (C), D4.A, K4.A2 (2)
TS1: MUX1.2 (S1), TS1.1 (VOUT)
TS2: MUX1.9 (S2), TS2.1 (VOUT)
TS3: MUX1.4 (S3), TS3.1 (VOUT)
TS4: MUX1.7 (S4), TS4.1 (VOUT)
T_SENS: C1.1, CON1.18, MUX1.8 (D)
VC1: CH1.BB1.P (B1.P), K1.14 (NO), K1.24 (NO)
VC2: CH1.BB2.P (B2.P), K2.14 (NO), K2.24 (NO)
VC3: CH2.BB1.P (B1.P), K3.14 (NO), K3.24 (NO)
VC4: CH2.BB2.P (B2.P), K4.14 (NO), K4.24 (NO)
VSE+: CON1.16, K1.21 (COM), K2.21 (COM), K3.21 (COM), K4.21 (COM)
VSE-: CON1.14, R5.2

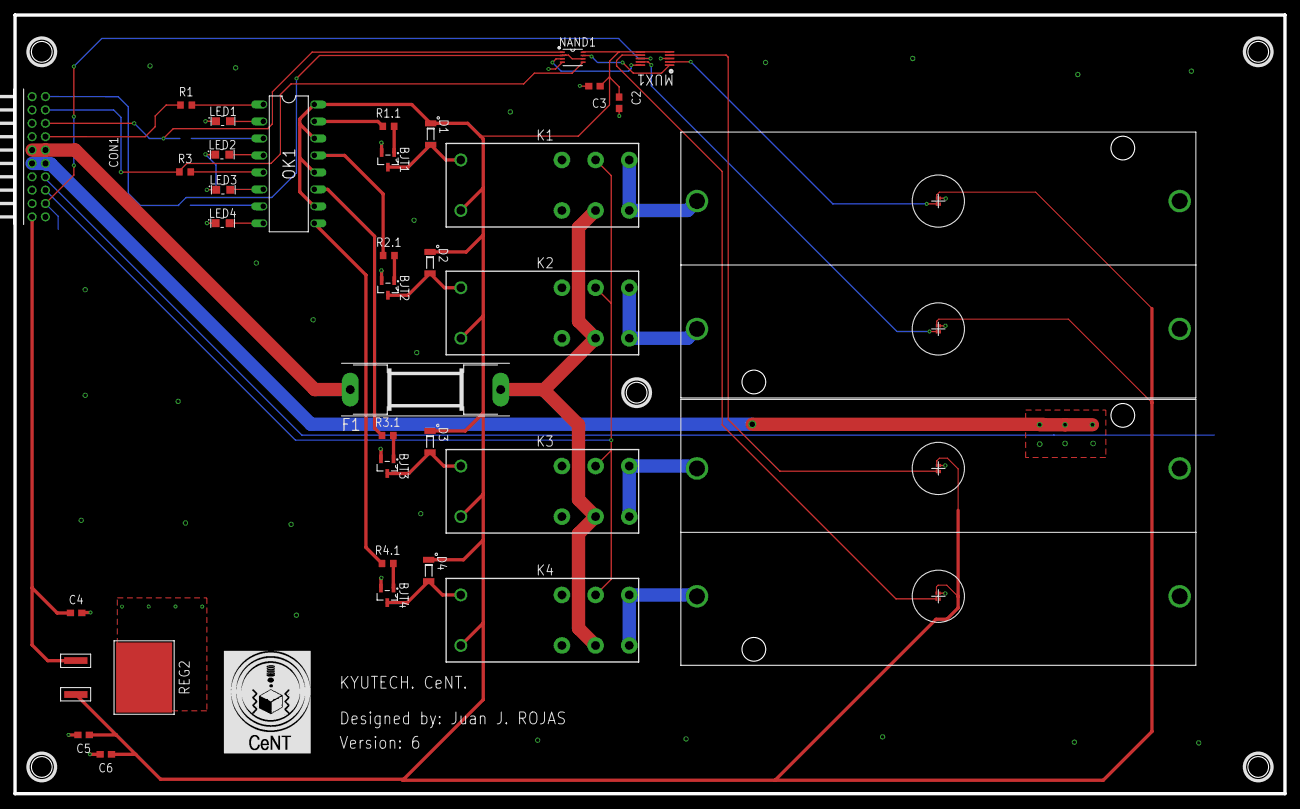
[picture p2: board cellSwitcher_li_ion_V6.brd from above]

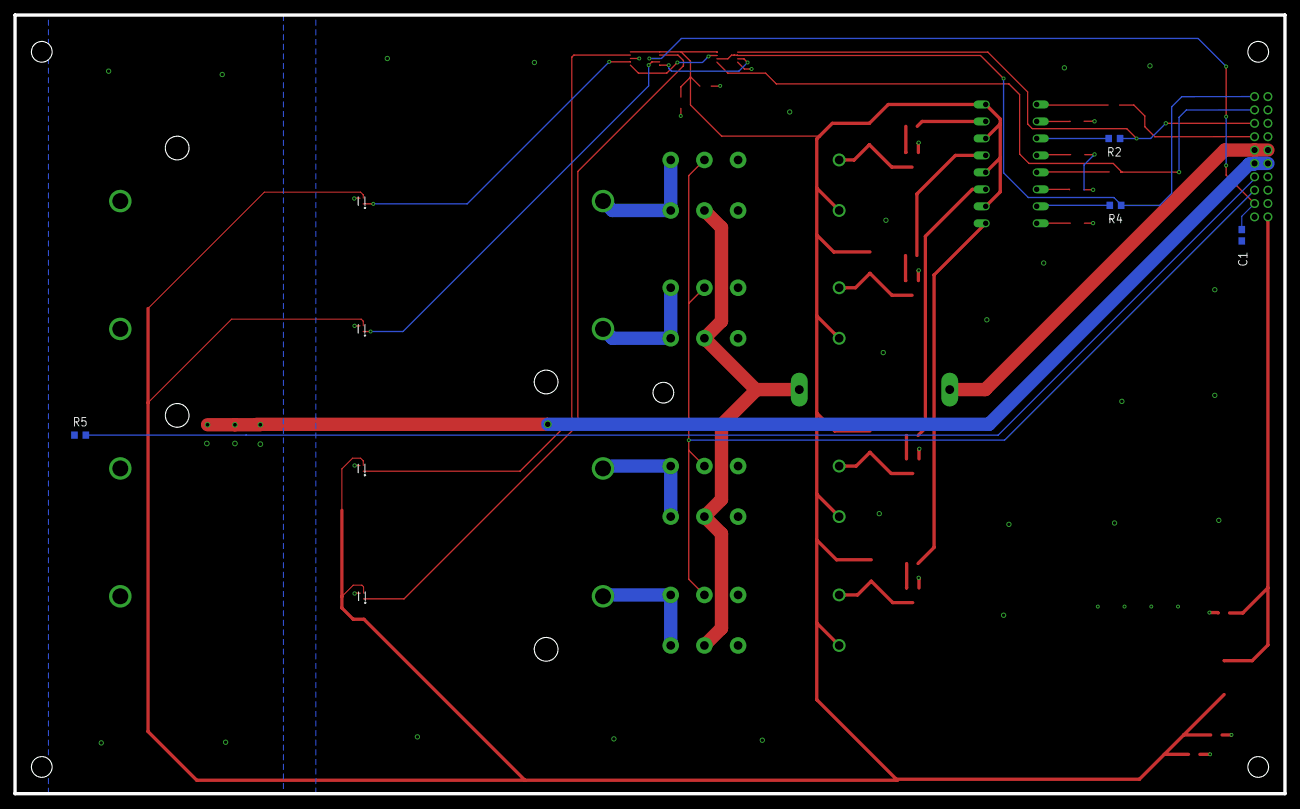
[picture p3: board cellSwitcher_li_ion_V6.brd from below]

Board: 2 copper layers, 190.0 x 116.5 mm, 43 parts (4 on the bottom side), 43 nets.

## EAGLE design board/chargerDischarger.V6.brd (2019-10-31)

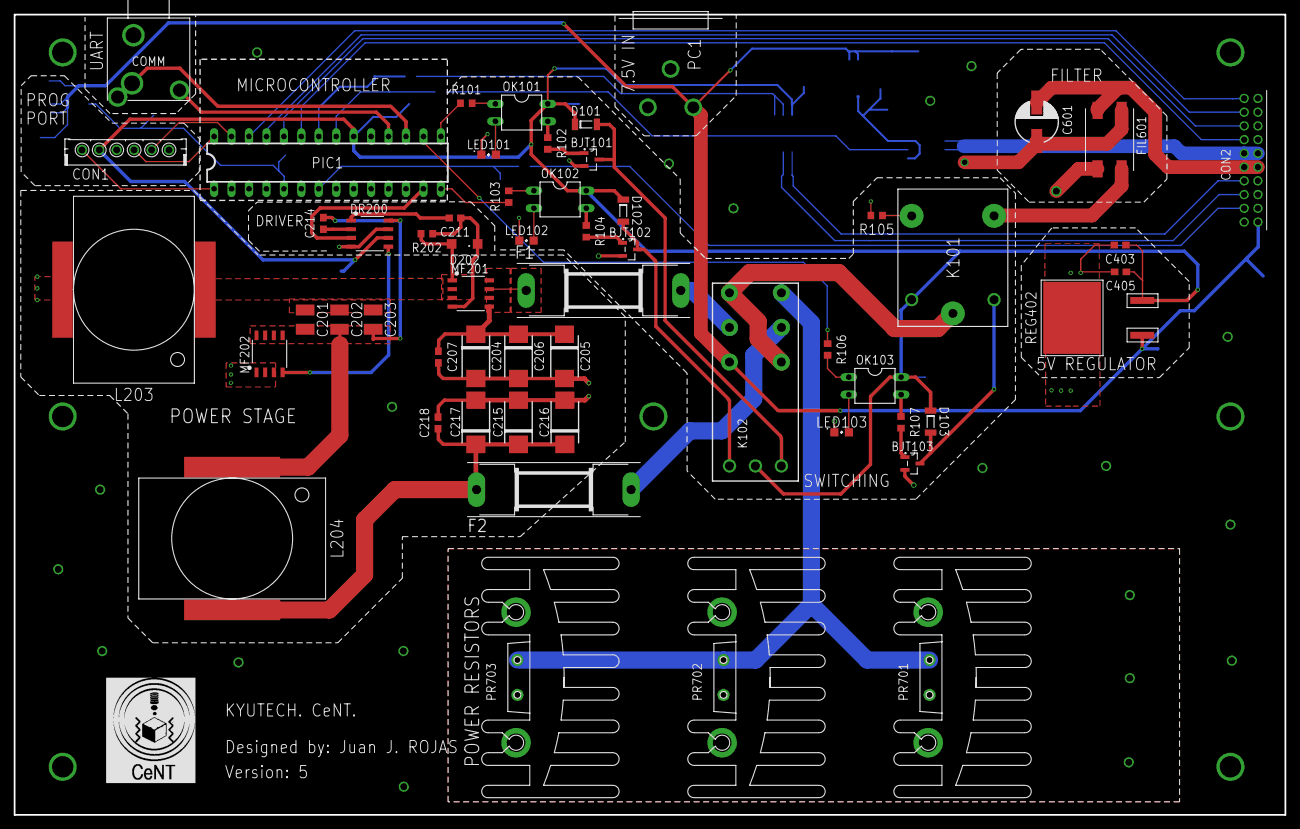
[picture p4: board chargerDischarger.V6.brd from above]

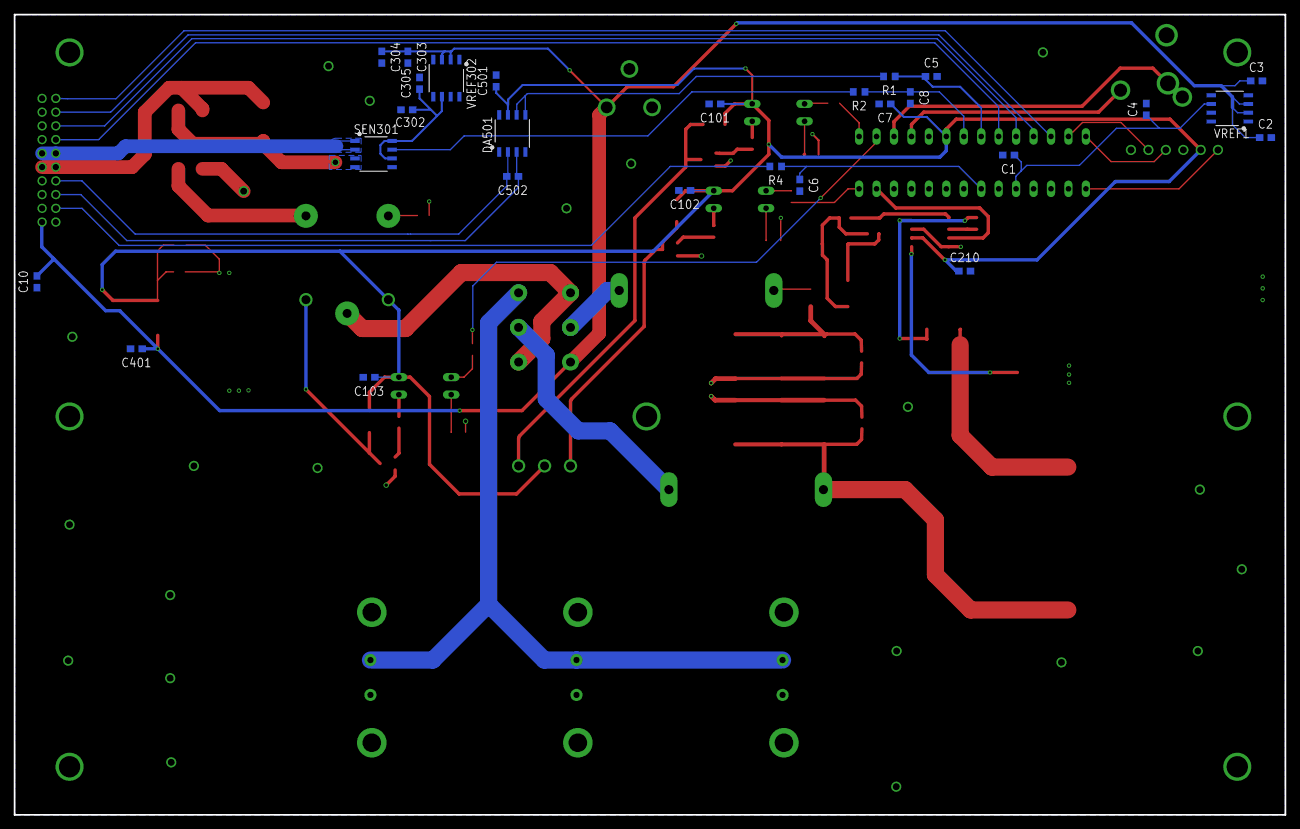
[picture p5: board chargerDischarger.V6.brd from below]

Board: 2 copper layers, 185.0 x 116.5 mm, 83 parts (27 on the bottom side), 58 nets.

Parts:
BJT101, BJT102, BJT103: BC818K-40; SOT-23
C1, C3, C6, C7, C101, C102, C103, C210, C214, C302, C304, C403: 1u; C0603
C2, C10, C303, C405: 10u; C0603
C4, C207, C218, C305, C501: 0.1u; C0603
C5, C8, C502: 1n; C0603
C201, C202, C203: 10u; C1210
C204, C205, C206, C215, C216, C217: 33u_Tan; C7343
C211: 10n; C0603
C401: 0.33u; C0603
C601: 100u; D6.3_AEC
COMM: AUDIO_JACK-3.5MM; KLBR4
CON1: B6B-EH-A
CON2: SQT-110-01-F-D-RA
D101, D102, D103: BAQ133; SOD08
D202: SOD123
DA501: MAX4198; SOIC-8
DR200: MCP14628-E/SN; SOIC-8
F1, F2: 4A; SH22,5
FIL601: ACM9070-701
K101: ORWH; ORWH-SS-105D1F
K102: RT424F05054; RT424F05
L203, L204: 68µ; 60B683C
LED101, LED102, LED103: LGR971; SML0805
MF201, MF202: SI4154DY; SOIC-8
OK101, OK102, OK103: PS2502-1; DIL04
PC1: 722RA
PIC1: PIC16F1786-SPDIP; SPDIP-28
PR701, PR702, PR703: 1; TO-220HEATSINK
R1, R2: 0; R0603
R4: 200; R0603
R101, R103, R106, R202: 1k; R0603
R102, R104, R107: 510; R0603
R105: 10M; R0603
REG402: NCV7805BD2TG; D2PAK-3
SEN301: ACS723-05AB-T; SOIC-8
VREF1, VREF302: REF195GSZ; SOIC-8

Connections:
7.5V: C2.1, C3.1, C10.2, C303.1, C304.1, C401.1, CON2.19, K102.22, PC1.PIN, REG402.1, VREF1.2, VREF1.3, VREF302.2, VREF302.3
+5V: C7.1, C101.1, C102.1, C103.1, C210.1, C403.1, C405.1, C501.1, CON1.2, D101.C, D102.C, D103.C, DA501.7, DR200.6, K101.B1, K102.A3, OK101.4, OK102.4, OK103.4, PIC1.20, REG402.3
BI_CURR_MEAS1:N$1: C302.1, C305.1, SEN301.6, SEN301.8, VREF302.6
C1_SW: CON2.8, PIC1.23
C2_SW: CON2.6, PIC1.24
C3_SW: CON2.4, PIC1.25
C4_SW: CON2.2, PIC1.26
CHAR: PIC1.15, R101.1
DISC: PIC1.14, R103.1
GND: BJT101.2, BJT102.2, BJT103.2, C1.2, C2.2, C3.2, C4.2, C5.2, C6.2, C7.2, C8.2, C10.1, C101.2, C102.2, C103.2, C204.-, C205.-, C206.-, C207.2, C210.2, C215.-, C216.-, C217.-, C218.2, C302.2, C303.2, C304.2, C305.2, C401.2, C403.2, C405.2, C501.2, COMM.S, CON1.3, CON2.1, CON2.3, CON2.5, CON2.7, CON2.13, CON2.15, CON2.17, CON2.20, DA501.1, DA501.4, DR200.4, DR200.7, FIL601.P$3, L203.2, LED101.C, LED102.C, LED103.C, MF202.1, MF202.2, MF202.3, PC1.SLEEVE, PC1.SLEEVE_SHUNT, PIC1.8, PIC1.19, PR701.D1, PR701.D2, PR701.R1, PR702.D1, PR702.D2, PR702.R1, PR703.D1, PR703.D2, PR703.R1, R105.2, REG402.4, SEN301.5, VREF1.4, VREF302.4
ICSPCLK: CON1.5, PIC1.27
ICSPDAT: CON1.4, PIC1.28
IN/OUT+: CON2.9, CON2.10, SEN301.1, SEN301.2
IN/OUT-: C601.NEG, CON2.11, CON2.12, FIL601.P$2
I_SENS: R2.2, SEN301.7
MCLR: CON1.1, PIC1.1
unnamed: C8.1, PIC1.21, R2.1
unnamed: C5.1, PIC1.22, R1.1
unnamed: C6.1, PIC1.7, R4.1
unnamed: C1.1, C4.1, PIC1.5, VREF1.6
unnamed: C601.POS, FIL601.P$1, SEN301.3, SEN301.4
unnamed: FIL601.P$4, K101.NO
unnamed: F1.2, K102.21
unnamed: F2.2, K102.11
ON/OFF: PIC1.16, R106.1
POWER_RESISTOR: K102.14, PR701.R2, PR702.R2, PR703.R2
PWM: DR200.3, PIC1.13
RX: COMM.B, COMM.R, PIC1.17
SWITCH1:N$1: BJT101.1, R102.2
SWITCH1:N$2: BJT101.3, D101.A, K102.A1
SWITCH1:N$3: LED102.A, OK102.2
SWITCH1:N$4: OK102.1, R103.2
SWITCH1:N$5: OK102.3, R104.1
SWITCH1:N$6: BJT102.1, R104.2
SWITCH1:N$7: BJT102.3, D102.A, K102.A2
SWITCH1:N$8: K101.NC, R105.1
SWITCH1:N$9: LED103.A, OK103.2
SWITCH1:N$10: OK103.1, R106.2
SWITCH1:N$11: LED101.A, OK101.2
SWITCH1:N$12: OK101.1, R101.2
SWITCH1:N$13: OK101.3, R102.1
SWITCH1:N$14: OK103.3, R107.1
SWITCH1:N$15: BJT103.1, R107.2
SWITCH1:N$16: BJT103.3, D103.A, K101.B2
SWITCH1:TEST: K101.COM, K102.12, K102.24
TX: COMM.T, PIC1.18
T_SENS: CON2.18, R4.2
VSE+: C502.1, CON2.16, DA501.3
VSE-: C502.2, CON2.14, DA501.2
V_SENS: DA501.5, DA501.6, R1.2
ZETA_CONV1:L1_IN1: C201.1, C202.1, C203.1, D202.A, L203.1, MF201.1, MF201.2, MF201.3, R202.2
ZETA_CONV1:L2_IN1: C201.2, C202.2, C203.2, C214.2, DR200.8, L204.1, MF202.5, MF202.6, MF202.7, MF202.8
ZETA_CONV1:N$10: DR200.5, MF202.4
ZETA_CONV1:N$28: C214.1, DR200.2
ZETA_CONV1:N$29: C211.2, DR200.1
ZETA_CONV1:N$30: C211.1, D202.C, MF201.4, R202.1
ZETA_IN: C204.+, C205.+, C206.+, C207.1, F1.1, MF201.5, MF201.6, MF201.7, MF201.8
ZETA_OUT: C215.+, C216.+, C217.+, C218.1, F2.1, L204.2

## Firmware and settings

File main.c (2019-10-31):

/**
 * @file
 * main.c
 * @author 
 * Juan J. Rojas
 * @date 
 * 7 Aug 2018
 * @brief 
 * Main source file. Includes the main loop and the interruption service routine. 
 * @par Institution:
 * LaSEINE / CeNT. Kyushu Institute of Technology.
 * @par Mail:
 * juan.rojas@tec.ac.cr
 * @par Git repository:
 * https://bitbucket.org/juanjorojash/cell_charger_discharger
 */

#include "charger_discharger.h"

/**@brief <b> This is the main function of the program. It initializes the system in every reset and takes care of several tasks that are excecuted every second. </b>
*/

void main(void) /// This function performs the folowing tasks:                     
{       
    initialize(); /// <ul> <li> Call the #initialize function
    __delay_ms(10);
    while(1) /// <li> <b> The main loop repeats the following forever: </b> 
    {
        if (SECF) /// <ul> <li> Check the #SECF flag, if it is set, 1 second has passed since last execution, so the folowing task are executed:
        {     
            SECF = 0; /// <ol> <li> Clear the #SECF flag to restart the 1 second timer
            scaling(); /// <li> Scale the average measured values by calling the #scaling function 
            log_control(); /// <li> Print the log in the serial terminal by calling the #log_control function
            cc_cv_mode(vavg, cvref, cmode); /// <li> Check if the system shall change to CV mode by calling the #cc_cv_mode function
            state_machine(); /// <li> Call the #state_machine function
            //temp_protection(); /// <li> Call the #temp_protection function </ol> </ul> </ul>
        }
	}
}

/**@brief <b> This is the interruption service function. It will interrupt the code whenever the Timer1 overflow (0.975625 milliseconds) or when any character is received from the serial terminal via UART. </b>
*/
void __interrupt() ISR(void) /// This function performs the folowing tasks: 
{
    char recep = 0;
    
    if(TMR1IF) /// <li> Check the @b Timer1 interrupt flag, if it is set, the folowing task are executed:
    {
        TMR1H = 0xE1; // TMR1 clock is Fosc/4= 8Mhz (Tick= 0.125us). TMR1IF is set when the 16-bit register overflows. 7805 x 0.125us = 0.975625 ms.
        TMR1L = 0x83;/// <ol> <li> Load the @b Timer1 16-bit register so it overflow every 0.975625 ms 
        TMR1IF = 0; /// <li> Clear the @b Timer1 interrupt flag
        v = read_ADC(V_CHAN); /// <li> Read the ADC channel #V_CHAN and store the value in #v. Using the #read_ADC() function
        i = read_ADC(I_CHAN); /// <li> Read the ADC channel #I_CHAN and store the value in #i. Using the #read_ADC() function
        i = (uint16_t) (abs ( 2048 - (int)i ) ); /// <li> Substract the 2.5V bias from #i, store the absolute value in #i   
        t = read_ADC(T_CHAN); /// <li> Read the ADC channel #T_CHAN and store the value in #t. Using the #read_ADC() function 
        if (conv) control_loop(); /// <li> Call the #control_loop() function
        calculate_avg(); /// <li> Call the #calculate_avg() function
        timing(); /// <li> Call the #timing() function
        if (TMR1IF) UART_send_string((char*)"TIMING_ERROR"); /// <li> If the @b Timer1 interrupt flag is set, there is a timing error, print "TIMING_ERROR" into the terminal. </ol>
    }

    if(RCIF)/// <li> Check the @b UART reception interrupt flag, if it is set, the folowing task are executed:
    {
        if(RC1STAbits.OERR) /// <ol> <li> Check for any errors and clear them
        {
            RC1STAbits.CREN = 0;  
            RC1STAbits.CREN = 1; 
        }
        while(RCIF) recep = RC1REG; /// <li> Store the received character
        switch (recep)
        {
        case 0x63: /// <li> If a @b "c" was received, the process shall stop, then:
            STOP_CONVERTER(); /// - Stop the converter by calling the #STOP_CONVERTER() macro
            state = STANDBY; /// - Go to #STANDBY state
            break;
        case 0x6E: /// <li> If @p an @b "n" was received, the system shall jump to the next cell, then:
            STOP_CONVERTER(); /// - Stop the converter by calling the #STOP_CONVERTER() macro
            state = ISDONE; /// - Go to #ISDONE state
            break;
        default: /// <li> In any other case, do nothing
            recep = 0; 
        } /// </ol> </ul>
    }  
}

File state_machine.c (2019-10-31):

/**
 * @file state_machine.c
 * @author Juan J. Rojas
 * @date 7 Aug 2018
 * @brief State machine source file for Charge and Discharge System.
 * @par Institution:
 * LaSEINE / CeNT. Kyushu Institute of Technology.
 * @par Mail (after leaving Kyutech):
 * juan.rojas@tec.ac.cr
 * @par Git repository:
 * https://bitbucket.org/juanjorojash/cell_charger_discharger
 */

#include "charger_discharger.h"

/**@brief This function contain the transition definition for the states of the machine.
*/
void state_machine()
{
    switch(state){
    /**The #STANDBY  state goes to the #fSTANDBY()  function.*/
            case STANDBY:
                fSTANDBY();
                SECF = 1; //THis makes the thing go inside the state machine
                break;   
    /**The #IDLE  state goes to the #fIDLE()  function.*/             
            case IDLE:
                fIDLE();
                break;
    /**The #PREDISCHARGE  and #DISCHARGE  states go to the #fDISCHARGE()  function.*/ 
            case PREDISCHARGE:
            case DISCHARGE:
                fDISCHARGE();
                break;
    /**And the #POSTCHARGE  and #CHARGE  states go to the #fCHARGE()  function.*/  
            case POSTCHARGE:  
            case CHARGE:   
                fCHARGE();  
                break;
    /**The #CS_DC_res , #DS_DC_res  and #PS_DC_res  states go to the #fDC_res()  function.*/
            case CS_DC_res:
            case DS_DC_res:
            case PS_DC_res:
                fDC_res();
                break;
    /**The #WAIT  state goes to the #fWAIT()  function.*/
            case WAIT:    
                fWAIT();
                break;
    /**The #ISDONE  state goes to the #fISDONE()  function.*/
            case ISDONE:    
                fISDONE();
                break;
    /**The #FAULT  state goes to the #fFAULT()  function.*/
            case FAULT:    
                fFAULT();
                break;
    }
}

/**@brief This function define the #STANDBY  state of the state machine.
*/
void fSTANDBY()
{   
    STOP_CONVERTER(); /// * Stop the converter by calling the #STOP_CONVERTER() macro
    RCIE = 0; /// * Disable the USART reception interrupts to avoid interference with the setting of parameters in the #STANDBY state
    TMR1ON = 0; ///* Disable the Timer1 to avoid interference
    option = 0; /// * Initialize #option to 0
    cell_max = 0; /// * Initialize #cell_max to 0
    cell_count = 1; /// * Initialize #cell_count to '1'
    LINEBREAK;
    #if (LI_ION_CHEM) /// If #LI_ION_CHEM  is set to @b 1 and #NI_MH_CHEM  is set to @b 0, the folowing message will be displayed:
    UART_send_string((char*)chem_def_liion); /// * <tt> Chemistry defined as Li-Ion </tt>
    LINEBREAK;
    #elif (NI_MH_CHEM) /// If #NI_MH_CHEM  is set to @b 1 and #LI_ION_CHEM  is set to @b 0, the folowing message will be displayed:
    UART_send_string((char*)chem_def_nimh); /// * <tt> Chemistry defined as Ni-MH </tt>
    LINEBREAK;
    #endif
    param(); /// Call the #param() function
}
/**@brief This function define the IDLE state of the state machine.
*/
void fIDLE()
{
    /**At first, the function will call the #Start_state_machine()  function.*/
    start_state_machine();
    /**Then, it will call the #Converter_settings()  function.*/
    converter_settings(); 
    /**Then, it will enable the USART reception interrupts to give the possibility to the user to press
    @b ESC to cancel or @b n to go to the next cell, at any time during the testing process*/            
    interrupt_enable();
}

/**@brief This function define the IDLE state of the state machine.
*/
void fCHARGE()
{
    LOG_ON(); /// * Activate the logging by calling #LOG_ON() macro
    conv = 1; /// * Activate control loop by setting #conv
    if (vavg < 900) //&& (qavg > 1)) /// If #vavg is below 0.9V
    {
        state = FAULT; /// * Go to #FAULT state
        UART_send_string((char*)cell_below_str); /// * Send a warning message
        LINEBREAK;
    }
    if (state == CHARGE){ /// If the #state is #CHARGE
        #if (LI_ION_CHEM) 
        /// If the chemistry is Li-Ion
        if ((iavg < EOC_current)  && (qavg > 100)) /// * If #iavg is below #EOC_current then
        {                
            prev_state = state; /// -# Set #prev_state equal to #state
            state = WAIT; /// -# Else, go to #WAIT state
            wait_count = WAIT_TIME; /// -# Set #wait_count equal to #WAIT_TIME
            STOP_CONVERTER(); /// -# Stop the converter by calling #STOP_CONVERTER() macro
        }
        #elif (NI_MH_CHEM) 
        /// If the chemistry is Ni-MH
        if (((vavg < (vmax - Ni_MH_EOC_DV)) && (qavg > 100)) || minute >= timeout)
        {
            prev_state = state; /// -# Set #prev_state equal to #state
            state = WAIT; /// -# Else, go to #WAIT state
            wait_count = WAIT_TIME; /// -# Set #wait_count equal to #WAIT_TIME
            STOP_CONVERTER(); /// -# Stop the converter by calling #STOP_CONVERTER() macro
        }
        #endif   
    } 
    if (state == POSTCHARGE){
        #if (LI_ION_CHEM) 
        if (qavg >= ( (capacity * 10) / 2 ) && ((minute + second) >= 1)){
            prev_state = state;
            state = WAIT;
            wait_count = WAIT_TIME;
            STOP_CONVERTER();
        }
        #elif (NI_MH_CHEM)
        if (qavg >= ( (capacity * 10) / 2 ) || (unsigned) minute >= timeout){
            prev_state = state;
            state = WAIT;
            wait_count = WAIT_TIME;
            STOP_CONVERTER();
        }
        #endif  
    }    
}

/**@brief This function define the IDLE state of the state machine.
*/
void fDISCHARGE()
{
    LOG_ON(); /// * Activate the logging by calling #LOG_ON() macro
    conv = 1; /// * Activate control loop by setting #conv
    if ( vavg < EOD_voltage ) /// * If #vavg is below #EOD_voltage then
    {
        prev_state = state; /// -# Set #prev_state equal to #stat
        state = WAIT; /// -# Else, go to #WAIT state                  
        wait_count = WAIT_TIME; /// -# Set #wait_count equal to #WAIT_TIME
        STOP_CONVERTER(); /// -# Stop the converter by calling #STOP_CONVERTER() macro  
    }
}
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
